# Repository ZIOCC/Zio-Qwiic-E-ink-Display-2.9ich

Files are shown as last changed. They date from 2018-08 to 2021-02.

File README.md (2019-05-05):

# Zio Qwiic E-Ink Display 2.9"

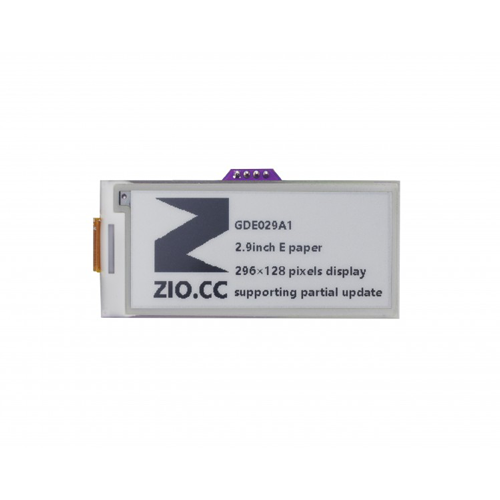
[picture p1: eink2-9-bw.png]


> This product can be available for purchase [here](https://www.smart-prototyping.com/%20Zio-Qwiic-E-ink-Display-I2C).

##### Description

An E-ink module is great, how about to make it even nicer? Here we go! Instead of using SPI protocol, we created this I2C E-ink display to join our Qwiic family. So you can just daisy chain this E-ink display just like the other Qwiic modules!

Nothing fancy here, we add a STM32 as the gateway, it can communicate with I2C system, then drive E-ink display to refresh content by SPI protocol.

In order to inherit the ultra low power consuming feature of the E-ink display, we let the STM32 IC go into deep sleep mode (2uA power consuming) and add an I2C chip that is used for waking STM32 up.

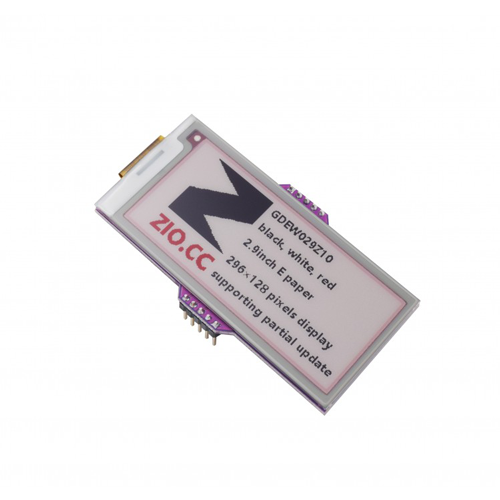
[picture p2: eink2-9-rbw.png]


> This product can be available for purchase [here](https://www.smart-prototyping.com/Zio-E-Ink-Display-2-9-in-Black-White-Red).

Tired of using boring black and white E-ink display? Let’s add a spicy color to it! This is a 2.9 inch Red-Black-white E-ink display with 296x128 pixels resolution.

The red is good, but not always, because of the limitation of the E-ink display technology, the refresh time for Red E-ink display is much longer than Black-White version, this E-ink display refresh time is 12 secs! Let’s hope the technology will solve this soon, until then, enjoy this red E-ink first!

##### Usage:

* Price tag for supermarket, shop
* Industry controller device
* Low power Consumption product and project

###### About Zio
> Zio is a new line of open sourced, compact, and grid layout boards, fully integrated for Arduino and Qwiic ecosystem. Designed ideally for wearables, robotics, small-space limitations or other on the go projects. Check out other awesome Zio products [here](https://www.smart-prototyping.com/Zio).

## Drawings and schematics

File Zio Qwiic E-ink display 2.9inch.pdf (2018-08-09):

1uF ±10% 25V | 1uF ±10% ⁵⁰V 1uF ±10% ⁵⁰V GND
GND100nF ±10% ⁵⁰V | 100nF ±10% ⁵⁰V | 10K ±1% | 10K ±1% | 10K ±1%

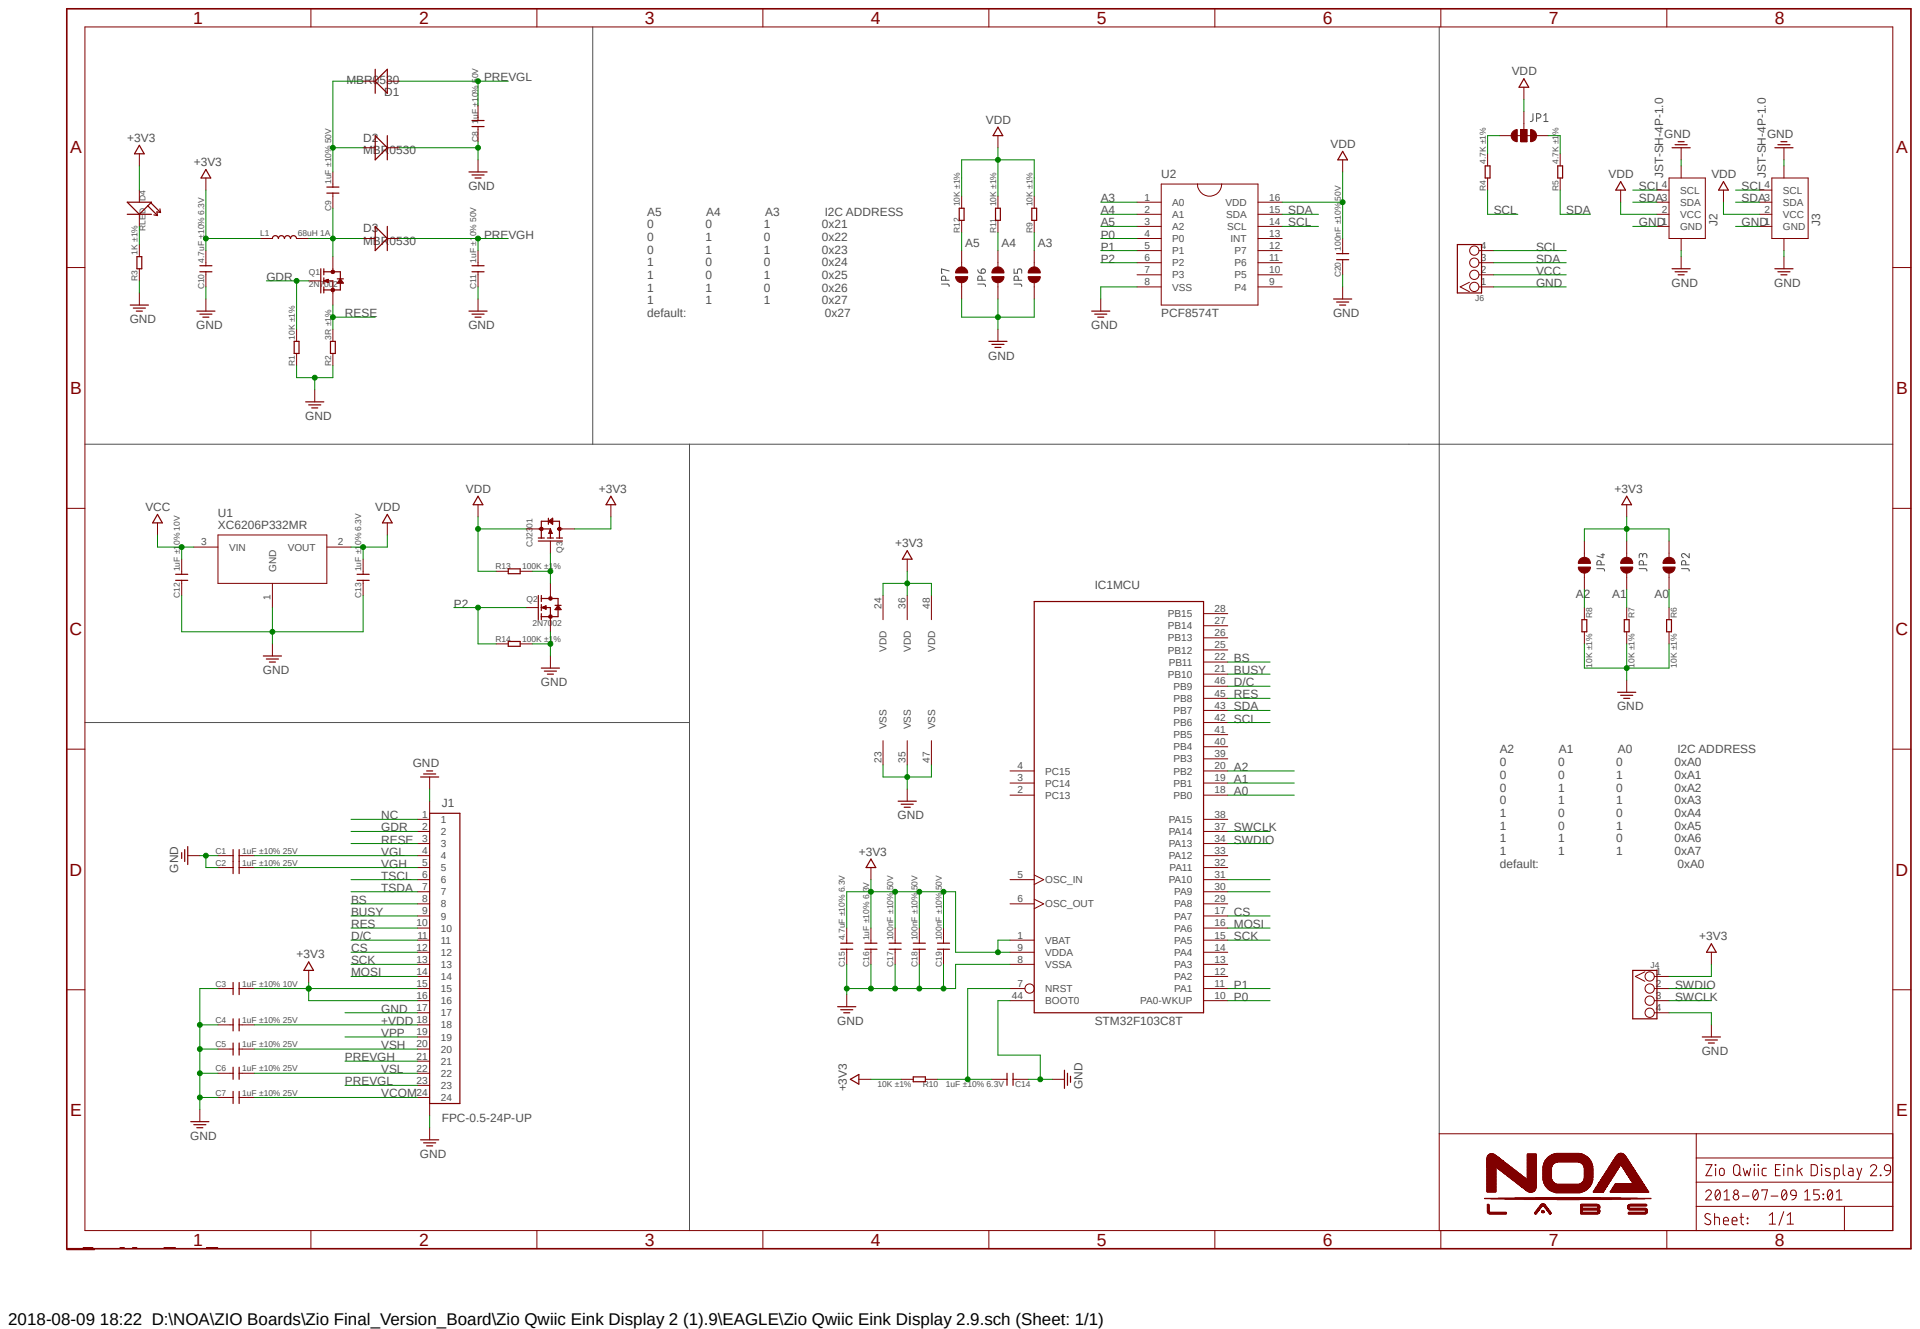
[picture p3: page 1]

VDD | VDD

4 J3 JST⁻SH⁻⁴P⁻¹.0 GND

2018-08-09 18:22 D:\NOA\ZIO Boards\Zio Final_Version_Board\Zio Qwiic Eink Display 2 (1).9\EAGLE\Zio Qwiic Eink Display 2.9.sch (Sheet: 1/1)

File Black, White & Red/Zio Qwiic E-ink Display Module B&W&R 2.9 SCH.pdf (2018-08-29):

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

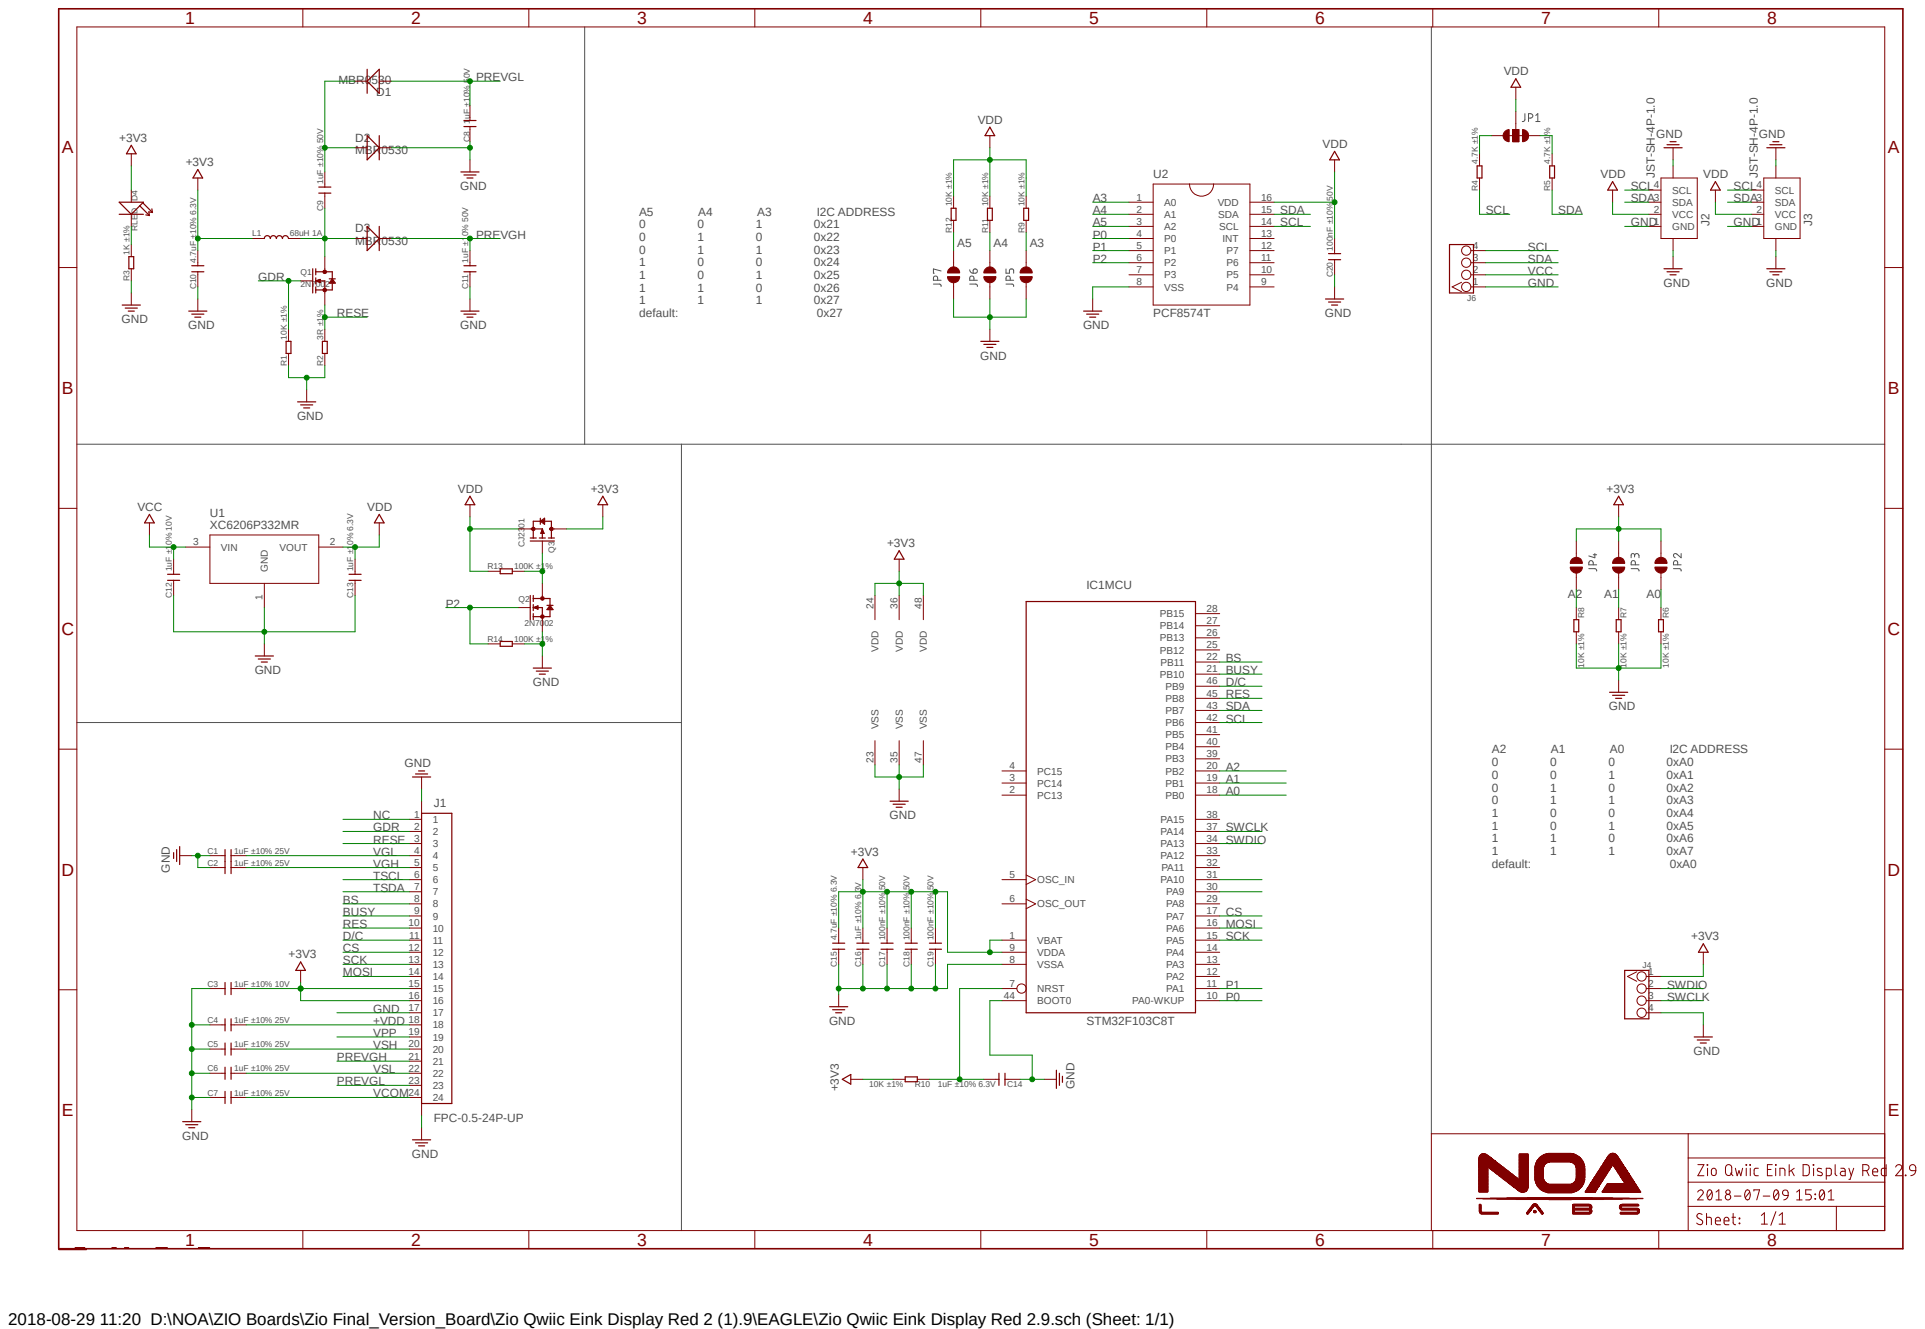
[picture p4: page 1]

VDD | VDD

4 J3 JST⁻SH⁻⁴P⁻¹.0 GND

2018-08-29 11:20 D:\NOA\ZIO Boards\Zio Final_Version_Board\Zio Qwiic Eink Display Red 2 (1).9\EAGLE\Zio Qwiic Eink Display Red 2.9.sch (Sheet: 1/1)

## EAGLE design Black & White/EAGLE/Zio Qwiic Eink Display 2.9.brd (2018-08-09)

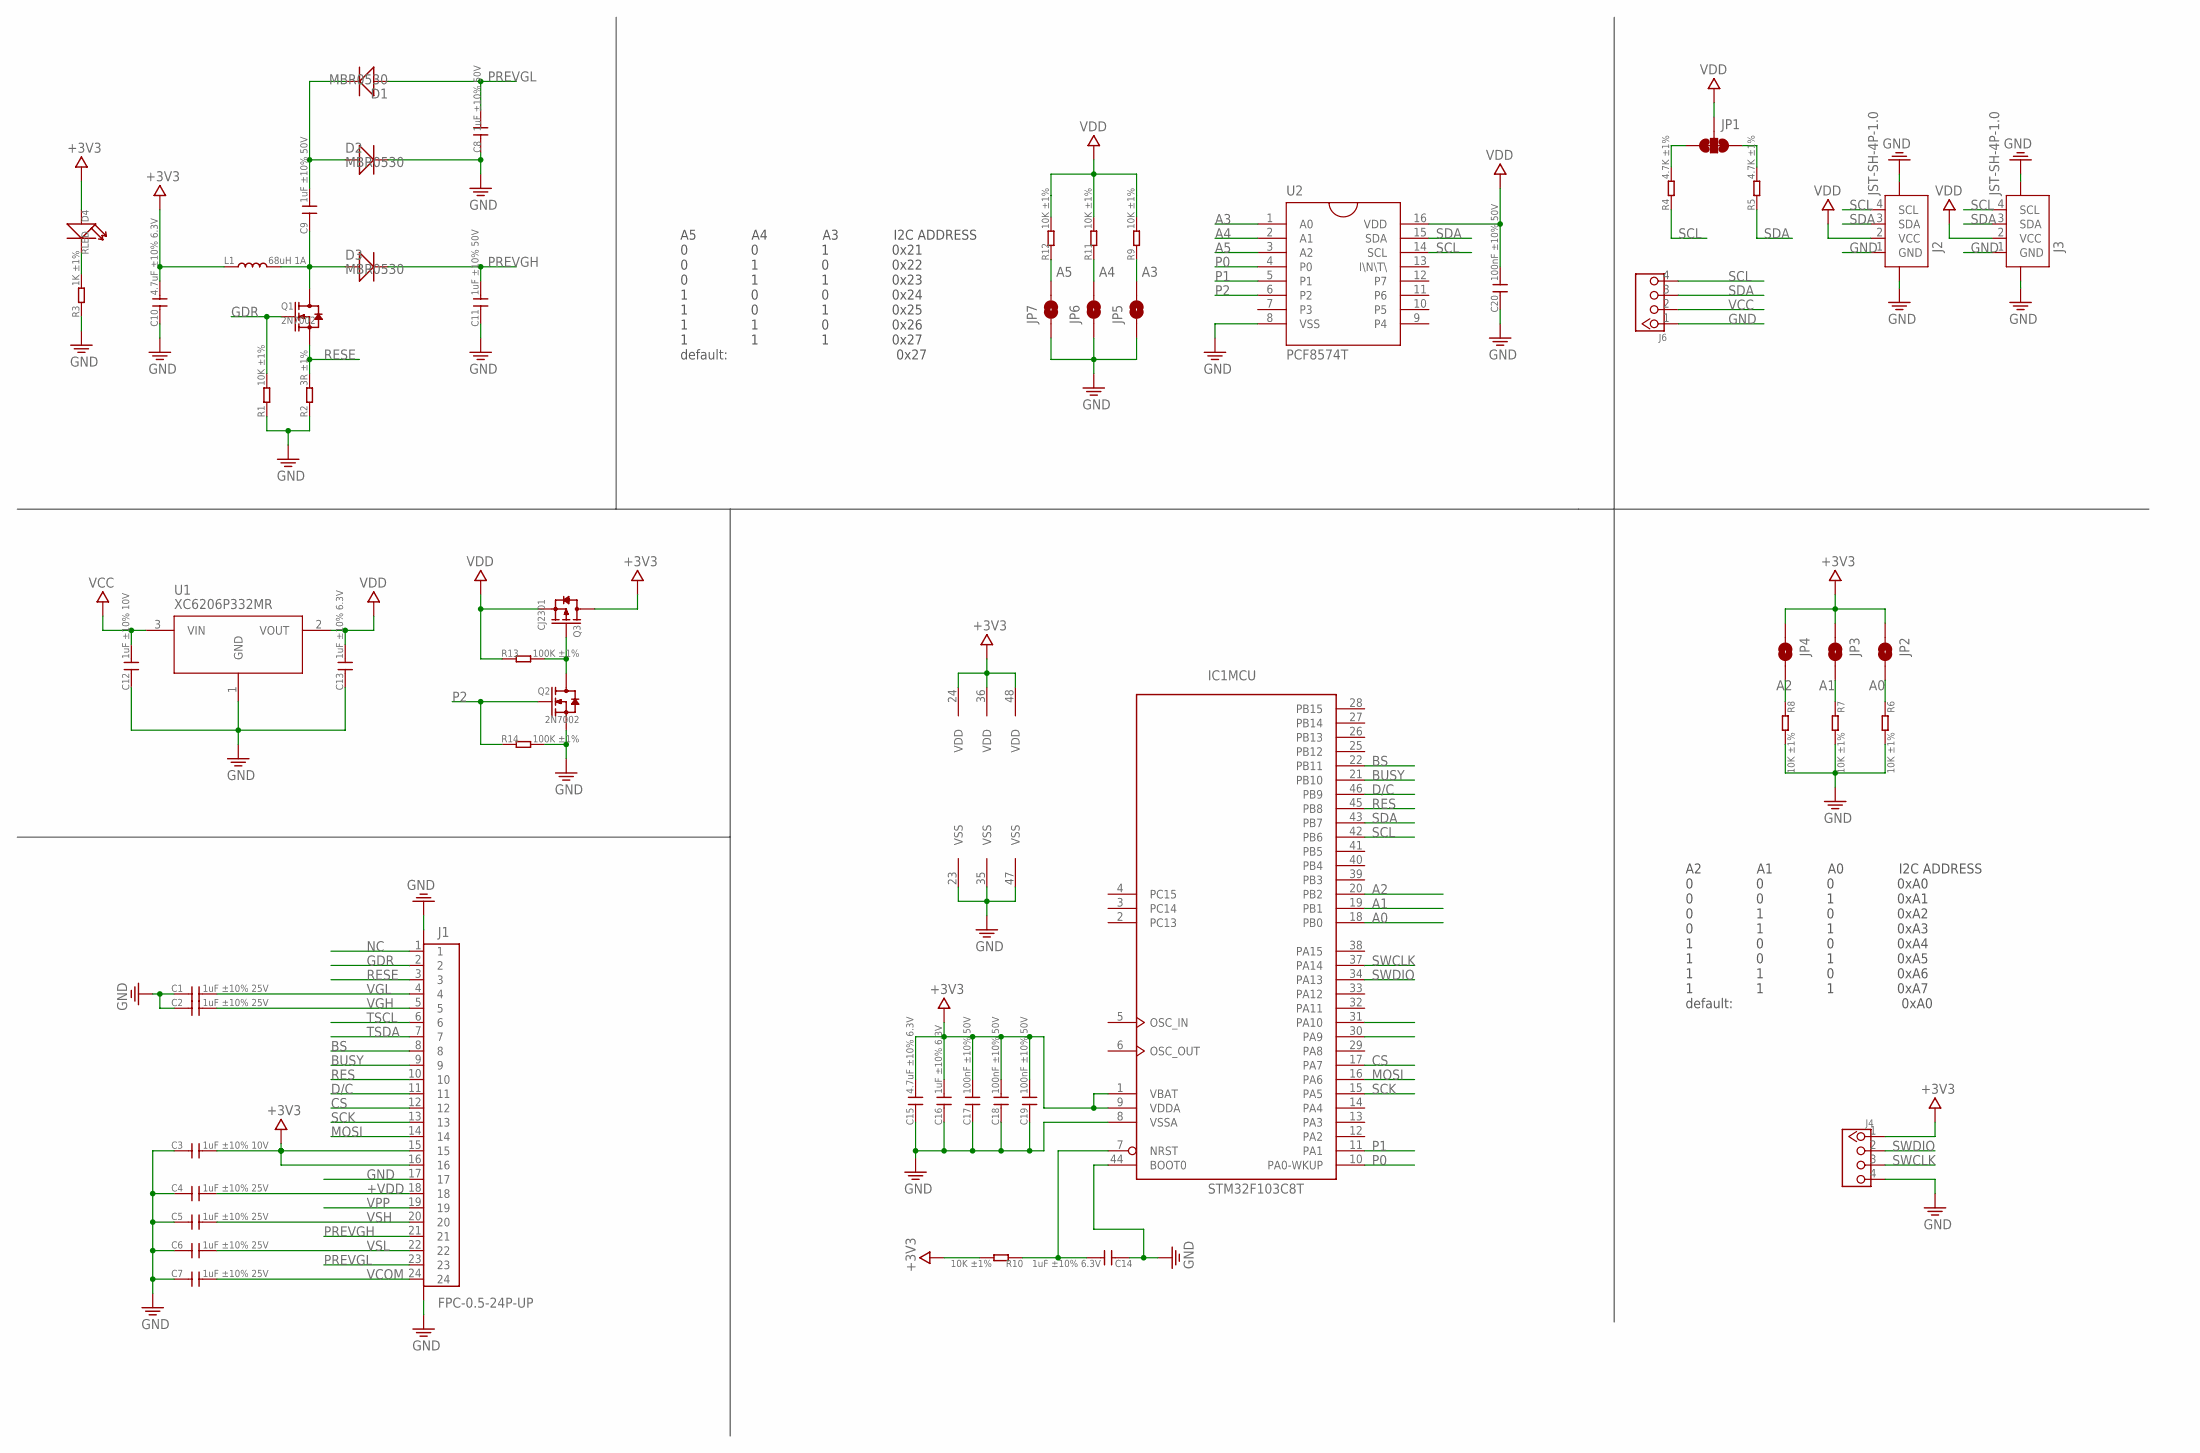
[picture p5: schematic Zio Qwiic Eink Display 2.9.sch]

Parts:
C1, C2, C4, C5, C6, C7: 1uF ±10% 25V; C0603
C3, C12: 1uF ±10% 10V; C0603
C8: 1uF ±10% 50V; 0603
C9, C11: 1uF ±10% 50V; C0603
C10, C15: 4.7uF ±10% 6.3V; C0603
C13, C14, C16: 1uF ±10% 6.3V; C0603
C17, C18, C19, C20: 100nF ±10% 50V; C0603
D1, D2, D3: MBR0530; SOD123
D4: RLED; LED-0603
IC1: STM32F103C8T; LQFP48
J1: FPC-0.5-24P-UP; FPC-0.5-24P_UP
J2, J3: JST-SH-4P-1.0; JST-SH-4P
J4: HEADER-4P-2.54-SMD; 4P-2.54-SMD-180
J6: HEADER-4P-60/35MIL; 4P-65/35MIL
JP1: SMT-JUMPER_3_2-NC_TRACE
JP2, JP3, JP4, JP5, JP6, JP7: JUMPER-SMT_2_NC_PASTE_NOCREM; SMT-JUMPER_2_NC_PASTE_SILK_NOCREM
L1: 68uH 1A; L3012
Q1, Q2: 2N7002; SOT23
Q3: CJ2301; SOT23
R1, R6, R7, R8, R9, R10, R11, R12: 10K ±1%; R0603
R2: 3R ±1%; R0603
R3: 1K ±1%; R0603
R4, R5: 4.7K ±1%; R0603
R13, R14: 100K ±1%; R0603
U1: XC6206P332MR; SOT23
U2: PCF8574T; SO16-W

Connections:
+3V3: C3.2, C10.2, C15.2, C16.2, C17.2, C18.2, C19.2, D4.+, IC1.1 (VBAT), IC1.9 (VDDA), IC1.24 (VDD), IC1.36 (VDD), IC1.48 (VDD), J1.15, J1.16, J4.1, JP2.1, JP3.1, JP4.1, L1.1, Q3.3 (D), R10.2
+VDD: C4.2, J1.18
A0: IC1.18 (PB0), JP2.2, R6.1
A1: IC1.19 (PB1), JP3.2, R7.1
A2: IC1.20 (PB2), JP4.2, R8.1
A3: JP5.2, R9.1, U2.1 (A0)
A4: JP6.2, R11.1, U2.2 (A1)
A5: JP7.2, R12.1, U2.3 (A2)
BS: IC1.22 (PB11), J1.8
BUSY: IC1.21 (PB10), J1.9
CS: IC1.17 (PA7), J1.12
D/C: IC1.46 (PB9), J1.11
GDR: J1.2, Q1.1 (G), R1.2
GND: C1.1, C2.1, C3.1, C4.1, C5.1, C6.1, C7.1, C8.1, C10.1, C11.1, C12.1, C13.1, C14.1, C15.1, C16.1, C17.1, C18.1, C19.1, C20.1, D2.-, IC1.8 (VSSA), IC1.23 (VSS), IC1.35 (VSS), IC1.44 (BOOT0), IC1.47 (VSS), J1.17, J1.25 (G1), J1.26 (G2), J2.1 (GND), J2.NC1 (5), J2.NC2 (6), J3.1 (GND), J3.NC1 (5), J3.NC2 (6), J4.4, J6.1, JP5.1, JP6.1, JP7.1, Q2.2 (S), R1.1, R2.1, R3.1, R6.2, R7.2, R8.2, R14.2, U1.1 (GND), U2.8 (VSS)
MOSI: IC1.16 (PA6), J1.14
unnamed: C9.2, D1.-, D2.+
unnamed: C9.1, D3.+, L1.2, Q1.3 (D)
unnamed: C14.2, IC1.7 (NRST), R10.1
unnamed: JP1.3, R4.2
unnamed: D4.-, R3.2
unnamed: JP1.1, R5.2
unnamed: Q2.3 (D), Q3.1 (G), R13.2
NC: J1.1
P0: IC1.10 (PA0-WKUP), U2.4 (P0)
P1: IC1.11 (PA1), U2.5 (P1)
P2: Q2.1 (G), R14.1, U2.6 (P2)
PREVGH: C11.2, D3.-, J1.21
PREVGL: C8.2, D1.+, J1.23
RES: IC1.45 (PB8), J1.10
RESE: J1.3, Q1.2 (S), R2.2
SCK: IC1.15 (PA5), J1.13
SCL: IC1.42 (PB6), J2.4 (SCL), J3.4 (SCL), J6.4, R4.1, U2.14 (SCL)
SDA: IC1.43 (PB7), J2.3 (SDA), J3.3 (SDA), J6.3, R5.1, U2.15 (SDA)
SWCLK: IC1.37 (PA14), J4.3
SWDIO: IC1.34 (PA13), J4.2
TSCL: J1.6
TSDA: J1.7
VCC: C12.2, J6.2, U1.3 (VIN)
VCOM: C7.2, J1.24
VDD: C13.2, C20.2, J2.2 (VCC), J3.2 (VCC), JP1.2, Q3.2 (S), R9.2, R11.2, R12.2, R13.1, U1.2 (VOUT), U2.16 (VDD)
VGH: C2.2, J1.5
VGL: C1.2, J1.4
VPP: J1.19
VSH: C5.2, J1.20
VSL: C6.2, J1.22

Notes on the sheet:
A2 A1 A0 I2C ADDRESS 0 0 0 0xA0 0 0 1 0xA1 0 1 0 0xA2 0 1 1 0xA3 1 0 0 0xA4 1 0 1 0xA5 1 1 0 0xA6 1 1 1 0xA7 default: 0xA0
A5 A4 A3 I2C ADDRESS 0 0 1 0x21 0 1 0 0x22 0 1 1 0x23 1 0 0 0x24 1 0 1 0x25 1 1 0 0x26 1 1 1 0x27 default: 0x27

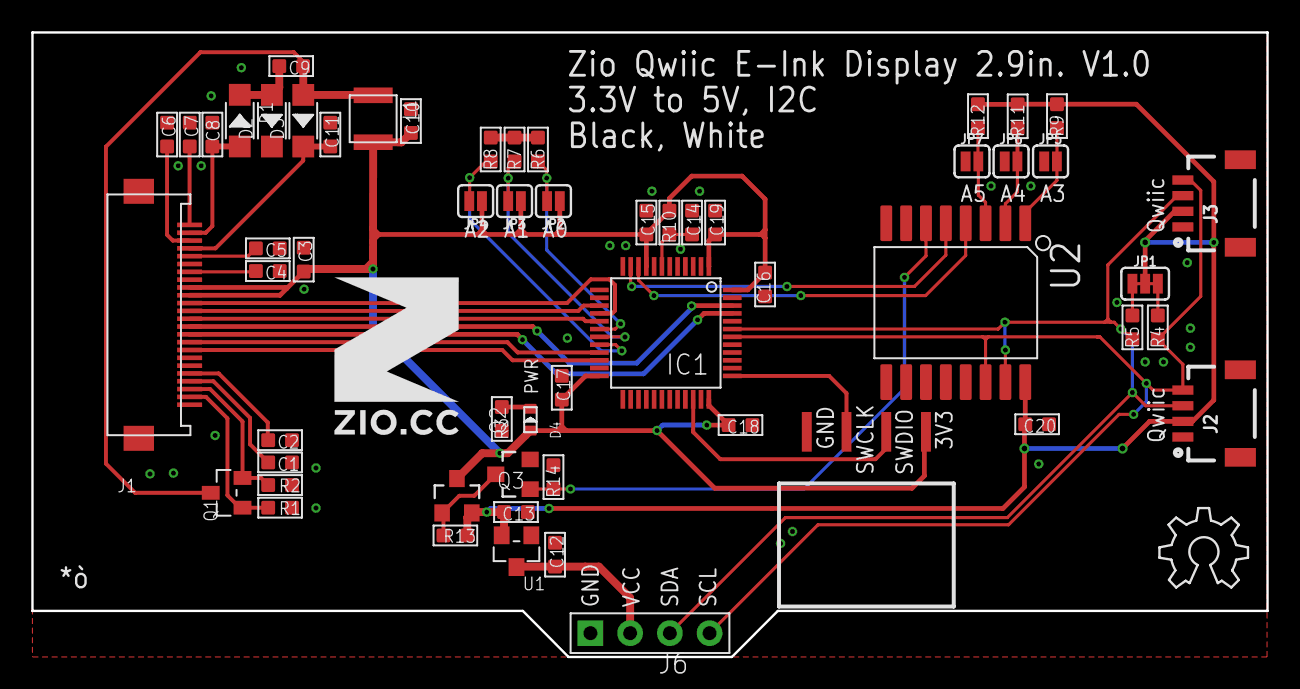
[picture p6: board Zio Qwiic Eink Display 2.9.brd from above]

Board: 2 copper layers, 79.0 x 39.9 mm, 59 parts (0 on the bottom side), 41 nets.

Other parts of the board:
U$10: OSHW_6X200_NOTEXT
U$20: 10MM

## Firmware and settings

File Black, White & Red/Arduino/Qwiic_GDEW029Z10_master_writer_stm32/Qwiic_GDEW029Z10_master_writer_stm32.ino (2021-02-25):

#include <Wire.h>
#include"I2CIO.h"
I2CIO IO;
const unsigned char  Pic_Black[] PROGMEM=
{
0XFF,0XFF,0XFF,0XFF,0XFF,0XFF,0XFF,0XFF,0XFF,0XFF,0XFF,0XFF,0XFF,0XFF,0XFF,0XFF,
0XFF,0XFF,0XFF,0XFF,0XFF,0XFF,0XFF,0XFF,0XFF,0XFF,0XFF,0XFF,0XFF,0XFF,0XFF,0XFF,
0XFF,0XFF,0XFF,0XFF,0XFF,0XFF,0XFF,0XFF,0XFF,0XFF,0XFF,0XFF,0XFF,0XFF,0XFF,0XFF,
0XFF,0XFF,0XFF,0XFF,0XFF,0XFF,0XFF,0XFF,0XFF,0XFF,0XFF,0XFF,0XFF,0XFF,0XFF,0XFF,
0XFF,0XFF,0XFF,0XFF,0XFF,0XFF,0XFF,0XFF,0XFF,0XFF,0XFF,0XFF,0XFF,0XFF,0XFF,0XFF,
0XFF,0XFF,0XFF,0XFF,0XFF,0XFF,0XFF,0XFF,0XFF,0XFF,0XFF,0XFF,0XFF,0XFF,0XFF,0XFF,
0XFF,0XFF,0XFF,0XFF,0XFF,0XFF,0XFF,0XFF,0XFF,0XFF,0XFF,0XFF,0XFF,0XFF,0XFF,0XFF,
0XFF,0XFF,0XFF,0XFF,0XFF,0XFF,0XFF,0XFF,0XFF,0XFF,0XFF,0XFF,0XFF,0XFE,0X3F,0XFF,
0XFF,0XFF,0XFF,0XFF,0XFF,0XFF,0XFF,0XFF,0XFF,0XFF,0XFF,0XFF,0XFF,0XFC,0X27,0XFF,
0XFF,0XFF,0XFF,0XFF,0XFF,0XFF,0XFF,0XFF,0XFF,0XFF,0XFF,0XFF,0XFF,0XFC,0XA7,0XFF,
0XFF,0XFF,0XFF,0XFF,0XFF,0XFF,0XFF,0XFF,0XFF,0XFF,0XFF,0XFF,0XFF,0XFC,0XA7,0XFF,
0XFF,0XFF,0XFF,0XFF,0XFF,0XFF,0XFF,0XFF,0XFF,0XFF,0XFF,0XFF,0XFF,0XFC,0XA7,0XFF,
0XFF,0XFF,0XFF,0XFF,0XFF,0XFF,0XFF,0XFF,0XFF,0XFF,0XFF,0XFF,0XFF,0XFE,0X07,0XFF,
0XFF,0XFF,0XFF,0XFF,0XFF,0XFF,0XFF,0XFF,0XFF,0XFF,0XFF,0XFF,0XFF,0XFF,0X0F,0XFF,
0XFF,0XFF,0XFF,0XFF,0XFF,0XFF,0XFF,0XFF,0XFF,0XFF,0XFF,0XFF,0XFF,0XFF,0XFF,0XFF,
0XFF,0XFF,0XFF,0XFF,0XFF,0XFF,0XFF,0XFF,0XFF,0XFF,0XFF,0XFF,0XFF,0XFC,0XE7,0XFF,
0XFF,0XFF,0XFF,0XFF,0XFF,0XFF,0XFF,0XFF,0XFF,0XFF,0XFF,0XFF,0XFF,0XFC,0XE7,0XFF,
0XFF,0XFF,0XFF,0XFF,0XFF,0XFF,0XFF,0XFF,0XFF,0XFF,0XFF,0XFF,0XFF,0XF0,0X07,0XFF,
0XFF,0XFF,0XFF,0XFF,0XFF,0XFF,0XFF,0XFF,0XFF,0XFF,0XFF,0XFF,0XFF,0XF0,0X0F,0XFF,
0XFF,0XFF,0XFF,0XFF,0XFF,0XFF,0XFF,0XFF,0XFF,0XFF,0XFF,0XFF,0XFF,0XFC,0XFF,0XFF,
0XFF,0XFF,0XFF,0XFF,0XFF,0XFF,0XFF,0XFF,0XFF,0XFF,0XFF,0XFF,0XFF,0XFF,0XFF,0XFF,
0XFF,0XFF,0XFF,0XFF,0XFF,0XFF,0XFF,0XFF,0XFF,0XFF,0XFF,0XFF,0XFF,0XFE,0X07,0XFF,
0XFF,0XFF,0XFF,0XFF,0XFF,0XFF,0XFF,0XFF,0XFF,0XFF,0XFF,0XFF,0XFF,0XFC,0X07,0XFF,
0XFF,0XFF,0XFF,0XFF,0XFF,0XFF,0XFF,0XFF,0XFF,0XFF,0XFF,0XFF,0XFF,0XFC,0XAF,0XFF,
0XFF,0XFF,0XFF,0XFF,0XFF,0XFF,0XFF,0XFF,0XFF,0XFF,0XFF,0XFF,0XFF,0XFC,0XA7,0XFF,
0XFF,0XFF,0XFF,0XFF,0XFF,0XFF,0XFF,0XFF,0XFF,0XFF,0XFF,0XFF,0XFF,0XFC,0XA7,0XFF,
0XFF,0XFF,0XFF,0XFF,0XFF,0XFF,0XFF,0XFF,0XFF,0XFF,0XFE,0X3F,0XFF,0XFC,0X87,0XFF,
0XFF,0XFF,0XFF,0XFF,0XFF,0XFF,0XFF,0XFF,0XFF,0XFF,0XFE,0X07,0XFF,0XFF,0XCF,0XFF,
0XFF,0XFF,0XFF,0XFF,0XFF,0XFF,0XFF,0XFF,0XFF,0XFF,0XFF,0XE0,0XFF,0XFF,0XFF,0XFF,
0XFF,0XFF,0XFF,0XFF,0XFF,0XFF,0XFF,0XFF,0XFF,0XFF,0XFF,0XC0,0X7F,0XE0,0X07,0XFF,
0XFF,0XFF,0XFF,0XFF,0XFF,0XFF,0XFF,0XFF,0XFF,0XFF,0XFE,0X06,0X3F,0XE0,0X07,0XFF,
0XFF,0XFF,0XFF,0XFF,0XFF,0XFF,0XFF,0XFF,0XFF,0XFF,0XFE,0X1F,0X3F,0XFE,0XEF,0XFF,
0XFF,0XFF,0XFF,0XFF,0XFF,0XFF,0XFF,0XFF,0XFF,0XFF,0XFE,0XFF,0X3F,0XFC,0XE7,0XFF,
0XFF,0XFF,0XFF,0XFF,0XFF,0XFF,0XFF,0XFF,0XFF,0XFF,0XFF,0XFF,0XFF,0XFC,0XE7,0XFF,
0XFF,0XFF,0XFF,0XFF,0XFF,0XFF,0XFF,0XFF,0XFF,0XFF,0XFF,0X03,0XFF,0XFC,0X07,0XFF,
0XFF,0XFF,0XFF,0XFF,0XFF,0XFF,0XFF,0XFF,0XFF,0XFF,0XFE,0X03,0XFF,0XFF,0X0F,0XFF,
0XFF,0XFF,0XFF,0XFF,0XFF,0XFF,0XFF,0XFF,0XFF,0XFF,0XFE,0X57,0XFF,0XFF,0XFF,0XFF,
0XFF,0XFF,0XFF,0XFF,0XFF,0XFF,0XFF,0XFF,0XFF,0XFF,0XFE,0X53,0XFF,0XFF,0XFF,0XFF,
0XFF,0XFF,0XFF,0XFF,0XFF,0XFF,0XFF,0XFF,0XFF,0XFF,0XFE,0X53,0XFF,0XFE,0X1F,0XFF,
0XFF,0XFF,0XFF,0XFF,0XFF,0XFF,0XFF,0XFF,0XFF,0XFF,0XFE,0X43,0XFF,0XFC,0X07,0XFF,
0XFF,0XFF,0XFF,0XFF,0XFF,0XFF,0XFF,0XFF,0XFF,0XFF,0XFF,0XE7,0XFF,0XFC,0XE7,0XFF,
0XFF,0XFF,0XFF,0XFF,0XFF,0XFF,0XFF,0XFF,0XFF,0XFF,0XFF,0XFF,0XFF,0XFC,0XE7,0XFF,
0XFF,0XFF,0XFF,0XFF,0XFF,0XFF,0XFF,0XFF,0XFF,0XFF,0XF0,0X03,0XFF,0XFE,0XEF,0XFF,
0XFF,0XFF,0XFF,0XFF,0XFF,0XFF,0XFF,0XFF,0XFF,0XFF,0XF0,0X03,0XFF,0XFC,0X00,0XFF,
0XFF,0XFF,0XFF,0XFF,0XFF,0XFF,0XFF,0XFF,0XFF,0XFF,0XFF,0XFF,0XFF,0XFC,0X00,0XFF,
0XFF,0XFF,0XFF,0XFF,0XFF,0XFF,0XFF,0XFF,0XFF,0XFF,0XFF,0XFF,0XFF,0XFF,0XFF,0XFF,
0XFF,0XFF,0XFF,0XFF,0XFF,0XFF,0XFF,0XFF,0XFF,0XFF,0XFF,0X0F,0XFF,0XFF,0XFF,0XFF,
0XFF,0XFF,0XFF,0XFF,0XFF,0XFF,0XFF,0XFF,0XFF,0XFF,0XFE,0X03,0XFF,0XFC,0X07,0XFF,
0XFF,0XFF,0XFF,0XFF,0XFF,0XFF,0XFF,0XFF,0XFF,0XFF,0XFE,0X73,0XFF,0XFC,0X07,0XFF,
0XFF,0XFF,0XFF,0XFF,0XFF,0XFF,0XFF,0XFF,0XFF,0XFF,0XFE,0X73,0XFF,0XFF,0XEF,0XFF,
0XFF,0XFF,0XFF,0XFF,0XFF,0XFF,0XFF,0XFF,0XFF,0XFF,0XFF,0X77,0XFF,0XFF,0XE7,0XFF,
0XFF,0XFF,0XFF,0XFF,0XFF,0XFF,0XFF,0XFF,0XFF,0XFF,0XFE,0X00,0X7F,0XFC,0X07,0XFF,
0XFF,0XFF,0XFF,0XFF,0XFF,0XFF,0XFF,0XFF,0XFF,0XFF,0XFE,0X00,0X7F,0XFC,0X0F,0XFF,
0XFF,0XFF,0XFF,0XFF,0XFF,0XFF,0XFF,0XFF,0XFF,0XFF,0XFF,0XFF,0XFF,0XFF,0XFF,0XFF,
0XFF,0XFF,0XFF,0XFF,0XFF,0XFF,0XFF,0XFF,0XFF,0XFF,0XFE,0X67,0XFF,0XFF,0XFF,0XFF,
0XFF,0XFF,0XFF,0XFF,0XFF,0XFF,0XFF,0XFF,0XFF,0XFF,0XFE,0X43,0XFF,0XFF,0XFF,0XFF,
0XFF,0XFF,0XFF,0XFF,0XFF,0XFF,0XFF,0XFF,0XFF,0XFF,0XFE,0X43,0XFF,0XFF,0XFF,0XFF,
0XFF,0XFF,0XFF,0XFF,0XFF,0XFF,0XFF,0XFF,0XFF,0XFF,0XFE,0X13,0XFF,0XFF,0XFF,0XFF,
0XFF,0XFF,0XFF,0XFF,0XFF,0XFF,0XFF,0XFF,0XFF,0XFF,0XFF,0X13,0XFF,0XFF,0XFF,0XFF,
0XFF,0XFF,0XFF,0XFF,0XFF,0XFF,0XFF,0XFF,0XFF,0XFF,0XFF,0XFF,0XFF,0XE0,0X07,0XFF,
0XFF,0XFF,0XFF,0XFF,0XFF,0XFF,0XFF,0XFF,0XFF,0XFF,0XFF,0XFF,0XFF,0XE0,0X07,0XFF,
0XFF,0XFF,0XFF,0XFF,0XFF,0XFF,0XFF,0XFF,0XFF,0XFF,0XF2,0X03,0XFF,0XFF,0XFF,0XFF,
0XFF,0XFF,0XFF,0XFF,0XFF,0XFF,0XFF,0XFF,0XFF,0XFF,0XF2,0X03,0XFF,0XFF,0XFF,0XFF,
0XFF,0XFF,0XFF,0XFF,0XFF,0XFF,0XFF,0XFF,0XFF,0XFF,0XFF,0XFF,0XFF,0XFE,0X07,0XFF,
0XFF,0XFF,0XFF,0XFF,0XFF,0XFF,0XFF,0XFF,0XFF,0XFF,0XFF,0XFF,0XFF,0XFC,0X07,0XFF,
0XFF,0XFF,0XFF,0XFF,0XFF,0XFF,0XFF,0XFF,0XFF,0XFF,0XF0,0X03,0XFF,0XFC,0XAF,0XFF,
0XFF,0XFF,0XFF,0XFF,0XFF,0XFF,0XFF,0XFF,0XFF,0XFF,0XF0,0X03,0XFF,0XFC,0XA7,0XFF,
0XFF,0XFF,0XFF,0XFF,0XFF,0XFF,0XFF,0XFF,0XFF,0XFF,0XFF,0X77,0XFF,0XFC,0XA7,0XFF,
0XFF,0XFF,0XFF,0XFE,0X00,0X7F,0XFF,0XFF,0XFF,0XFF,0XFE,0X73,0XFF,0XFC,0X87,0XFF,
0XFF,0XFF,0XFF,0XFE,0X00,0X7F,0XFF,0XFF,0XFF,0XFF,0XFE,0X73,0XFF,0XFF,0XCF,0XFF,
0XFF,0XFF,0XFF,0XFF,0XEE,0XFF,0XFF,0XFF,0XFF,0XFF,0XFE,0X03,0XFF,0XFF,0XFF,0XFF,
0XFF,0XFF,0XFF,0XFF,0XCE,0X7F,0XFF,0XFF,0XFF,0XFF,0XFF,0X87,0XFF,0XE4,0X07,0XFF,
0XFF,0XFF,0XFF,0XFF,0XCE,0X7F,0XFF,0XFF,0XFF,0XFF,0XFF,0XFF,0XFF,0XE4,0X07,0XFF,
0XFF,0XFF,0XFF,0XFF,0XC0,0X7F,0XFF,0XFF,0XFF,0XFF,0XFF,0XFF,0XFF,0XFF,0XFF,0XFF,
0XFF,0XFF,0XFF,0XFF,0XF0,0XFF,0XFF,0XFF,0XFF,0XFF,0XFF,0XFF,0XFF,0XFC,0XE7,0XFF,
0XFF,0XFF,0XFF,0XFF,0XFF,0XFF,0XFF,0XFF,0XFF,0XFF,0XFF,0XFF,0XFF,0XFC,0XE7,0XFF,
0XFF,0XFF,0XFF,0XFF,0XE3,0XFF,0XFF,0XFF,0XFF,0XFF,0XFF,0XFF,0XFF,0XF0,0X07,0XFF,
0XFF,0XFF,0XFF,0XFF,0XC2,0X7F,0XFF,0XE7,0XFF,0XFF,0XFE,0X67,0XFF,0XF0,0X0F,0XFF,
0XFF,0XFF,0XFF,0XFF,0XCA,0X7F,0XFF,0XF7,0XFF,0XFF,0XFE,0X43,0XFF,0XFC,0XFF,0XFF,
0XFF,0XFF,0XFF,0XFF,0XCA,0X7F,0XFF,0XE0,0X3F,0XFF,0XFE,0X43,0XFF,0XFF,0XFF,0XFF,
0XFF,0XFF,0XFF,0XFF,0XCA,0X7F,0XFF,0XE0,0X3F,0XFF,0XFE,0X13,0XFF,0XFC,0XFF,0XFF,
0XFF,0XFF,0XFF,0XFF,0XE0,0X7F,0XFF,0XFF,0XFF,0XFF,0XFF,0X13,0XFF,0XFE,0XFF,0XFF,
0XFF,0XFF,0XFF,0XFF,0XF0,0XFF,0XFF,0XF1,0XFF,0XFF,0XFF,0XFF,0XFF,0XFC,0X07,0XFF,
0XFF,0XFF,0XFF,0XFF,0XFF,0XFF,0XFF,0XE1,0X3F,0XFF,0XFF,0XFF,0XFF,0XFC,0X07,0XFF,
0XFF,0XFF,0XFF,0XFF,0XFF,0XFF,0XFF,0XE5,0X3F,0XFF,0XF0,0X03,0XFF,0XFF,0XFF,0XFF,
0XFF,0XFF,0XFF,0XFF,0XCF,0XFF,0XFF,0XE5,0X3F,0XFF,0XF0,0X03,0XFF,0XFF,0XFF,0XFF,
0XFF,0XFF,0XFF,0XFF,0XEF,0XFF,0XFF,0XE5,0X3F,0XFF,0XFF,0XFF,0XFF,0XFE,0X07,0XFF,
0XFF,0XFF,0XFF,0XFF,0XC0,0X7F,0XFF,0XF0,0X3F,0XFF,0XFF,0X1F,0XFF,0XFC,0X07,0XFF,
0XFF,0XFF,0XFF,0XFF,0XC0,0X7F,0XFF,0XF8,0X7F,0XFF,0XFE,0X13,0XFF,0XFC,0XAF,0XFF,
0XFF,0XFF,0XFF,0XFF,0XFF,0XFF,0XFF,0XFF,0XFF,0XFF,0XFE,0X53,0XFF,0XFC,0XA7,0XFF,
0XFF,0XE0,0X7F,0XFF,0XFF,0XFF,0XFF,0XFF,0XFF,0XFF,0XFE,0X53,0XFF,0XFC,0XA7,0XFF,
0XFF,0XC0,0X3F,0XFF,0XFF,0XFF,0XFF,0XF0,0XFF,0XFF,0XFE,0X53,0XFF,0XFC,0X87,0XFF,
0XFF,0X8F,0X1F,0XFF,0XFF,0XFF,0XFF,0XE0,0X3F,0XFF,0XFF,0X03,0XFF,0XFF,0XCF,0XFF,
0XFF,0X9F,0X9F,0XFF,0XFF,0XFF,0XFF,0XE7,0X3F,0XFF,0XFF,0X87,0XFF,0XFF,0XFF,0XFF,
0XFF,0X8F,0X1F,0XFF,0XFF,0XFF,0XFF,0XE7,0X3F,0XFF,0XFF,0XFF,0XFF,0XFE,0X1F,0XFF,
0XFF,0XC0,0X3F,0XFF,0XFF,0X7F,0XFF,0XF7,0X7F,0XFF,0XFF,0XFF,0XFF,0XFC,0X07,0XFF,
0XFF,0XE0,0X7F,0XFF,0XFF,0X1F,0XFF,0XE0,0X07,0XFF,0XFE,0XFB,0XFF,0XFC,0XE7,0XFF,
0XFF,0XFF,0XFF,0XFF,0XFF,0X1F,0XFF,0XE0,0X07,0XFF,0XFE,0X63,0XFF,0XFC,0XE7,0XFF,
0XFF,0XFF,0XFF,0XFF,0XE3,0XFF,0XFF,0XFF,0XFF,0XFF,0XFF,0X07,0XFF,0XFE,0XEF,0XFF,
0XFF,0XFF,0XFF,0XFF,0XC2,0X7F,0XFF,0XFF,0XFF,0XFF,0XFF,0X9F,0XFF,0XFC,0X00,0XFF,
0XFF,0XFF,0XFF,0XFF,0XCA,0X7F,0XFF,0XF0,0X3F,0XFF,0XFE,0X07,0XFF,0XFC,0X00,0XFF,
0XFF,0X80,0X1F,0XFF,0XCA,0X7F,0XFF,0XE0,0X3F,0XFF,0XFE,0X73,0XFF,0XFF,0XFF,0XFF,
0XFF,0X80,0X1F,0XFF,0XCA,0X7F,0XFF,0XE5,0X7F,0XFF,0XFE,0XFB,0XFF,0XFF,0XFF,0XFF,
0XFF,0XDF,0XFF,0XFF,0XE0,0X7F,0XFF,0XE5,0X3F,0XFF,0XFF,0XFF,0XFF,0XFF,0XFF,0XFF,
0XFF,0XCF,0XFF,0XFF,0XF0,0XFF,0XFF,0XE5,0X3F,0XFF,0XF2,0X03,0XFF,0XFF,0XFF,0XFF,
0XFF,0XFF,0XFF,0XFF,0XFF,0XFF,0XFF,0XE4,0X3F,0XFF,0XF2,0X03,0XFF,0XFF,0XFF,0XFF,
0XFF,0X9F,0X9F,0XFF,0XCE,0X7F,0XFF,0XFE,0X7F,0XFF,0XFF,0XFF,0XFF,0XFF,0XFF,0XFF,
0XFF,0X8F,0X9F,0XFF,0XCE,0X7F,0XFF,0XFF,0XFF,0XFF,0XFF,0XFF,0XFF,0XFC,0X03,0XFF,
0XFF,0X87,0X9F,0XFF,0X00,0X7F,0XFF,0XF0,0XFF,0XFF,0XFF,0X0F,0XFF,0XFC,0X01,0XFF,
0XFF,0X91,0X9F,0XFF,0X00,0XFF,0XFF,0XE0,0X3F,0XFF,0XFE,0X03,0XFF,0XFE,0XE8,0XFF,
0XFF,0X98,0X9F,0XFF,0XCF,0XFF,0XFF,0XE7,0X3F,0XFF,0XFE,0X73,0XFF,0XFC,0XE4,0XFF,
0XFF,0X9E,0X1F,0XFF,0XFF,0XFF,0XFF,0XE7,0X3F,0XFF,0XFE,0X73,0XFF,0XFC,0XE4,0XFF,
0XFF,0X9F,0X1F,0XFE,0X40,0X7F,0XFF,0XF7,0X7F,0XFF,0XFF,0X77,0XFF,0XFC,0X04,0XFF,
0XFF,0X9F,0X9F,0XFE,0X40,0X7F,0XFF,0XE0,0X07,0XFF,0XFE,0X00,0X7F,0XFF,0X0F,0XFF,
0XFF,0XFF,0XFF,0XFF,0XFF,0XFF,0XFF,0XE0,0X07,0XFF,0XFE,0X00,0X7F,0XFF,0XFF,0XFF,
0XFF,0XE0,0X7F,0XFF,0XFF,0XFF,0XFF,0XFF,0XFF,0XFF,0XFF,0XFF,0XFF,0XFF,0XFF,0XFF,
0XFF,0X80,0X3F,0XFF,0XE0,0X7F,0XFF,0XFF,0XFF,0XFF,0XFF,0XFF,0XFF,0XFE,0X07,0XFF,
0XFF,0X9D,0X9F,0XFF,0XC0,0X7F,0XFF,0XFF,0XFF,0XFF,0XFF,0XFF,0XFF,0XFC,0X07,0XFF,
0XFF,0X9C,0X9F,0XFF,0XCF,0XFF,0XFF,0XFF,0XFF,0XFF,0XFF,0XFF,0XFF,0XFC,0XFF,0XFF,
0XFF,0X80,0X9F,0XFF,0XEF,0XFF,0XFF,0XFF,0XFF,0XFF,0XFF,0XFF,0XFF,0XFE,0XFF,0XFF,
0XFF,0XE1,0XFF,0XFE,0X00,0X7F,0XFF,0X33,0X3F,0XFF,0XF8,0XC7,0XFF,0XFC,0X07,0XFF,
0XFF,0XFF,0XFF,0XFE,0X00,0X7F,0XFF,0X33,0X3F,0XFF,0XF0,0X03,0XFF,0XFC,0X07,0XFF,
0XFF,0XFF,0XFF,0XFF,0XFF,0XFF,0XFF,0X33,0X3F,0XFF,0XF7,0X3B,0XFF,0XFF,0XFF,0XFF,
0XFF,0XC3,0X9F,0XFF,0XC7,0XFF,0XFF,0X33,0X3F,0XFF,0XF7,0X3B,0XFF,0XFF,0XFF,0XFF,
0XFF,0X81,0X9F,0XFF,0XC0,0XFF,0XFF,0X00,0X3F,0XFF,0XF7,0X3B,0XFF,0XE4,0X07,0XFF,
0XFF,0X98,0X9F,0XFF,0XF8,0X7F,0XFF,0X00,0X3F,0XFF,0XF0,0X03,0XFF,0XE4,0X07,0XFF,
0XFF,0X9C,0X1F,0XFF,0XF8,0X7F,0XFF,0XFF,0XFF,0XFF,0XF8,0XC7,0XFF,0XFF,0XFF,0XFF,
0XFF,0X9E,0X1F,0XFF,0XC0,0XFF,0XFF,0XFF,0XFF,0XFF,0XFF,0XFF,0XFF,0XFC,0XE7,0XFF,
0XFF,0XCF,0X1F,0XFF,0XC7,0XFF,0XFF,0XFF,0XFF,0XFF,0XFF,0XFF,0XFF,0XFC,0XE7,0XFF,
0XFF,0XFF,0XFF,0XFF,0XC1,0XFF,0XFF,0XFF,0XFF,0XFF,0XF8,0X73,0XFF,0XF0,0X07,0XFF,
0XFF,0XE0,0X7F,0XFF,0XF8,0X7F,0XFF,0XFF,0XFF,0XFF,0XF0,0X33,0XFF,0XF0,0X0F,0XFF,
0XFF,0XC0,0X3F,0XFF,0XF8,0X7F,0XFF,0XFF,0XFF,0XFF,0XF3,0X13,0XFF,0XFC,0XFF,0XFF,
0XFF,0X8F,0X1F,0XFF,0XC1,0XFF,0XFF,0XF0,0X3F,0XFF,0XF3,0X83,0XFF,0XFF,0XFF,0XFF,
0XFF,0X9F,0X9F,0XFF,0XCF,0XFF,0XFF,0XE0,0X3F,0XFF,0XF3,0XC3,0XFF,0XFC,0XFF,0XFF,
0XFF,0X8F,0X1F,0XFF,0XFF,0XFF,0XFF,0XE7,0XFF,0XFF,0XF9,0XE3,0XFF,0XFE,0XFF,0XFF,
0XFF,0XC0,0X3F,0XFF,0XFF,0XFF,0XFF,0XF7,0XFF,0XFF,0XFF,0XFF,0XFF,0XFC,0X07,0XFF,
0XFF,0XE0,0X7F,0XFF,0XFF,0XFF,0XFF,0X00,0X3F,0XFF,0XFF,0XFF,0XFF,0XFC,0X07,0XFF,
0XFF,0XFF,0XFF,0XFF,0XFF,0XFF,0XFF,0X00,0X3F,0XFF,0XFF,0XFF,0XFF,0XFF,0XFF,0XFF,
0XFF,0X8F,0XFF,0XFF,0XFF,0XFF,0XFF,0XFF,0XFF,0XFF,0XFF,0XFF,0XFF,0XFF,0XFF,0XFF,
0XFF,0X81,0XFF,0XFF,0XFF,0X7F,0XFF,0XE6,0X3F,0XFF,0XF0,0X03,0XFF,0XFE,0X1F,0XFF,
0XFF,0XE0,0X1F,0XFF,0XFF,0X1F,0XFF,0XE7,0X3F,0XFF,0XF0,0X03,0XFF,0XFC,0X0F,0XFF,
0XFF,0XFE,0X1F,0XFF,0XFF,0X1F,0XFF,0XE7,0X3F,0XFF,0XFB,0XFF,0XFF,0XFC,0XE7,0XFF,
0XFF,0XFE,0X1F,0XFF,0XFF,0X7F,0XFF,0XE3,0X3F,0XFF,0XF9,0XFF,0XFF,0XFC,0XE7,0XFF,
0XFF,0XC0,0X7F,0XFF,0XCE,0X7F,0XFF,0XF0,0X7F,0XFF,0XFF,0XFF,0XFF,0XFC,0XE7,0XFF,
0XFF,0X83,0XFF,0XFF,0XC4,0X7F,0XFF,0XF8,0XFF,0XFF,0XFF,0XFF,0XFF,0XFE,0X07,0XFF,
0XFF,0X83,0XFF,0XFF,0XE0,0XFF,0XFF,0XFF,0XFF,0XFF,0XFF,0XFF,0XFF,0XFF,0X0F,0XFF,
0XFF,0XE0,0X7F,0XFF,0XFB,0XFF,0XFF,0XFF,0XFF,0XFF,0XFE,0XE7,0XFF,0XFF,0XFF,0XFF,
0XFF,0XFE,0X1F,0XFE,0X00,0X7F,0XFF,0XF0,0X3F,0XFF,0XFF,0X4F,0XFF,0XFF,0XFF,0XFF,
0XFF,0XFC,0X1F,0XFE,0X00,0X7F,0XFF,0XE0,0X3F,0XFF,0XFF,0X1F,0XFF,0XFE,0X1F,0XFF,
0XFF,0XC0,0X3F,0XFF,0XFF,0XFF,0XFF,0XE7,0XFF,0XFF,0XFF,0X9F,0XFF,0XFC,0X07,0XFF,
0XFF,0X81,0XFF,0XFF,0XCC,0X7F,0XFF,0XF7,0XFF,0XFF,0XFF,0X6F,0XFF,0XFC,0XE7,0XFF,
0XFF,0X9F,0XFF,0XFF,0XCE,0X7F,0XFF,0XE0,0X3F,0XFF,0XFE,0XF7,0XFF,0XFC,0XE7,0XFF,
0XFF,0X99,0X9F,0XFF,0XCE,0X7F,0XFF,0XE0,0X3F,0XFF,0XFF,0XFF,0XFF,0XFE,0XEF,0XFF,
0XFF,0X99,0X9F,0XFF,0XC6,0X7F,0XFF,0XFF,0XFF,0XFF,0XFF,0XFF,0XFF,0XFC,0X00,0XFF,
0XFF,0X99,0X9F,0XFF,0XE0,0XFF,0XFF,0XFF,0XFF,0XFF,0XFF,0X0F,0XFF,0XFC,0X00,0XFF,
0XFF,0X99,0X9F,0XFF,0XF1,0XFF,0XFF,0X20,0X3F,0XFF,0XF2,0X07,0XFF,0XFF,0XFF,0XFF,
0XFF,0X80,0X1F,0XFF,0XFF,0XFF,0XFF,0X20,0X3F,0XFF,0XF2,0X73,0XFF,0XFF,0XFF,0XFF,
0XFF,0X80,0X1F,0XFF,0XFF,0XFF,0XFF,0XFF,0XFF,0XFF,0XF2,0X73,0XFF,0XFE,0X1F,0XFF,
0XFF,0XFF,0XFF,0XFF,0XE0,0X7F,0XFF,0XFF,0XFF,0XFF,0XF1,0X73,0XFF,0XFC,0X07,0XFF,
0XFF,0XFF,0XFF,0XFF,0XC0,0X7F,0XFF,0XC0,0XFF,0XFF,0XF8,0X07,0XFF,0XFC,0XE7,0XFF,
0XFF,0XE0,0XFF,0XFF,0XCA,0XFF,0XFF,0X00,0X7F,0XFF,0XFE,0X0F,0XFF,0XFC,0XE7,0XFF,
0XFF,0XC0,0X3F,0XFF,0XCA,0X7F,0XFF,0X3B,0X3F,0XFF,0XFF,0XFF,0XFF,0XFE,0XEF,0XFF,
0XFF,0X8F,0X3F,0XFF,0XCA,0X7F,0XFF,0X39,0X3F,0XFF,0XFF,0XFF,0XFF,0XFC,0X00,0XFF,
0XFF,0X9F,0X9F,0XFF,0XC8,0X7F,0XFF,0X01,0X3F,0XFF,0XFC,0X0F,0XFF,0XFC,0X00,0XFF,
0XFF,0X9F,0X9F,0XFF,0XFC,0XFF,0XFF,0XC3,0XFF,0XFF,0XF0,0X07,0XFF,0XFF,0XFF,0XFF,
0XFF,0X9F,0X9F,0XFF,0XFF,0XFF,0XFF,0XFF,0XFF,0XFF,0XF3,0XB3,0XFF,0XFF,0XFF,0XFF,
0XFF,0X80,0X1F,0XFE,0X00,0X7F,0XFF,0XFF,0XFF,0XFF,0XF3,0X93,0XFF,0XFC,0X07,0XFF,
0XFF,0X80,0X1F,0XFE,0X00,0X7F,0XFF,0XFF,0X3F,0XFF,0XF0,0X13,0XFF,0XFC,0X07,0XFF,
0XFF,0XFF,0XFF,0XFF,0XFF,0XFF,0XFF,0XFF,0X3F,0XFF,0XFC,0X3F,0XFF,0XFF,0XEF,0XFF,
0XFF,0XFF,0XFF,0XFF,0XFF,0XFF,0XFF,0XFF,0XFF,0XFF,0XFF,0XFF,0XFF,0XFF,0XE7,0XFF,
0XFF,0X88,0X3F,0XFF,0XE1,0XFF,0XFF,0XFF,0XFF,0XFF,0XFF,0XFF,0XFF,0XFC,0X07,0XFF,
0XFF,0X98,0X1F,0XFF,0XC0,0X7F,0XFF,0X87,0X3F,0XFF,0XF8,0X73,0XFF,0XFC,0X0F,0XFF,
0XFF,0X99,0X9F,0XFF,0XCE,0X7F,0XFF,0X03,0X3F,0XFF,0XF0,0X33,0XFF,0XFF,0XFF,0XFF,
0XFF,0X99,0X9F,0XFF,0XCE,0X7F,0XFF,0X31,0X3F,0XFF,0XF3,0X13,0XFF,0XFC,0XCF,0XFF,
0XFF,0X9F,0X9F,0XFF,0XEE,0XFF,0XFF,0X38,0X3F,0XFF,0XF3,0X83,0XFF,0XFC,0X87,0XFF,
0XFF,0XCF,0X1F,0XFE,0X00,0X7F,0XFF,0X3C,0X3F,0XFF,0XF3,0XC3,0XFF,0XFC,0X87,0XFF,
0XFF,0XC0,0X3F,0XFE,0X00,0X7F,0XFF,0X9E,0X3F,0XFF,0XF9,0XE3,0XFF,0XFC,0X27,0XFF,
0XFF,0XF0,0X7F,0XFF,0XFF,0XFF,0XFF,0XFF,0XFF,0XFF,0XFF,0XFF,0XFF,0XFE,0X27,0XFF,
0XFF,0XFF,0XFF,0XFF,0XFF,0XFF,0XFF,0XFF,0XFF,0XFF,0XFF,0XFF,0XFF,0XFF,0XFF,0XFF,
0XFF,0XFF,0XFF,0XFF,0XFF,0XFF,0XFF,0XFF,0XFF,0XFF,0XFF,0XFF,0XFF,0XFF,0XFF,0XFF,
0XFF,0XFF,0XFF,0XFF,0XFF,0XFF,0XFF,0XFF,0XFF,0XFF,0XFF,0XFF,0XFF,0XFF,0XFF,0XFF,
0XFF,0XFF,0XFF,0XFF,0XFF,0XFF,0XFF,0XFF,0XFF,0XFF,0XFF,0XFF,0XFF,0XFF,0XFF,0XFF,
0XFF,0XFF,0XFF,0XFF,0XFF,0XFF,0XFF,0XFF,0XFF,0XFF,0XFF,0XFF,0XFF,0XFF,0XFF,0XFF,
0XFF,0XFF,0XFF,0XFF,0XFF,0XFF,0XFF,0XFF,0XFF,0XFF,0XFF,0XFF,0XFF,0XFF,0XFF,0XFF,
0XFF,0XFF,0XFF,0XFF,0XFF,0XFF,0XFF,0XFF,0XFF,0XFF,0XFF,0XFF,0XFF,0XFF,0XFF,0XFF,
0XF8,0X00,0X00,0X00,0X00,0X3F,0XFF,0XFF,0XFF,0XFF,0XFF,0XBF,0XFF,0XFF,0XFF,0XFF,
0XF8,0X00,0X00,0X00,0X00,0X3F,0XFF,0XFF,0XFF,0XFF,0XFF,0XBF,0XFF,0XFF,0XFF,0XFF,
0XF8,0X00,0X00,0X00,0X00,0X1F,0XFF,0XFF,0XFF,0XFF,0XFF,0X3F,0XF0,0X7F,0XC1,0XFF,
0XF8,0X00,0X00,0X00,0X00,0X1F,0XFF,0XFF,0XFF,0XFF,0XFF,0X3F,0XF0,0X7F,0XC1,0XFF,
0XF8,0X00,0X00,0X00,0X00,0X0F,0XFF,0XFF,0XFF,0XFF,0XFE,0X3F,0XF0,0XFF,0XE1,0XFF,
0XF8,0X00,0X00,0X00,0X00,0X0F,0XFF,0XFF,0XFF,0XFF,0XFE,0X3F,0XF0,0XFF,0XE0,0XFF,
0XF8,0X00,0X00,0X00,0X00,0X07,0XFF,0XFF,0XFF,0XFF,0XFE,0X3F,0XF0,0XFF,0XF0,0XFF,
0XF8,0X00,0X00,0X00,0X00,0X03,0XFF,0XFF,0XFF,0XFF,0XFC,0X3F,0XF0,0XFF,0XF0,0XFF,
0XF8,0X00,0X00,0X00,0X00,0X03,0XFF,0XFF,0XFF,0XFF,0XFC,0X3F,0XF0,0XFF,0XE0,0XFF,
0XF8,0X00,0X00,0X00,0X00,0X01,0XFF,0XFF,0XFF,0XFF,0XF8,0X3F,0XF0,0X7F,0XE0,0XFF,
0XF8,0X00,0X00,0X00,0X00,0X01,0XFF,0XFF,0XFF,0XFF,0XF8,0X3F,0XF0,0X7F,0XC1,0XFF,
0XF8,0X00,0X00,0X00,0X00,0X00,0XFF,0XFF,0XFF,0XFF,0XF8,0X3F,0XF0,0X3F,0X81,0XFF,
0XF8,0X00,0X00,0X00,0X00,0X00,0XFF,0XFF,0XFF,0XFF,0XF0,0X3F,0XF8,0X0E,0X01,0XFF,
0XF8,0X00,0X00,0X00,0X00,0X00,0X7F,0XFF,0XFF,0XFF,0XF0,0X3F,0XFC,0X00,0X03,0XFF,
0XF8,0X00,0X00,0X00,0X00,0X00,0X3F,0XFF,0XFF,0XFF,0XE0,0X3F,0XFC,0X00,0X03,0XFF,
0XF8,0X00,0X00,0X00,0X00,0X00,0X3F,0XFF,0XFF,0XFF,0XE0,0X3F,0XFE,0X00,0X07,0XFF,
0XF8,0X00,0X00,0X00,0X00,0X00,0X1F,0XFF,0XFF,0XFF,0XE0,0X3F,0XFF,0X80,0X0F,0XFF,
0XF8,0X00,0X00,0X00,0X00,0X00,0X1F,0XFF,0XFF,0XFF,0XE0,0X3F,0XFF,0XE0,0X7F,0XFF,
0XF8,0X00,0X00,0X00,0X00,0X00,0X1F,0XFF,0XFF,0XFF,0XE0,0X3F,0XFF,0XFF,0XFF,0XFF,
0XF8,0X00,0X00,0X00,0X00,0X00,0X0F,0XFF,0XFF,0XFF,0XC0,0X3F,0XFF,0XFF,0XFF,0XFF,
0XF8,0X00,0X00,0X00,0X00,0X00,0X0F,0XFF,0XFF,0XFF,0XC0,0X3F,0XF0,0X7F,0XC1,0XFF,
0XF8,0X00,0X00,0X00,0X00,0X00,0X07,0XFF,0XFF,0XFF,0X80,0X3F,0XF0,0XFF,0XE1,0XFF,
0XF8,0X00,0X00,0X00,0X00,0X00,0X07,0XFF,0XFF,0XFF,0X80,0X3F,0XF0,0XFF,0XE1,0XFF,
0XF8,0X00,0X00,0X00,0X00,0X00,0X03,0XFF,0XFF,0XFF,0X80,0X3F,0XF0,0XFF,0XF0,0XFF,
0XF8,0X00,0X00,0X00,0X00,0X00,0X01,0XFF,0XFF,0XFF,0X00,0X3F,0XF0,0XFF,0XF0,0XFF,
0XF8,0X00,0X00,0X00,0X00,0X00,0X01,0XFF,0XFF,0XFF,0X00,0X3F,0XF0,0XFF,0XF0,0XFF,
0XF8,0X00,0X00,0X00,0X00,0X00,0X00,0XFF,0XFF,0XFF,0X00,0X3F,0XF0,0XFF,0XE0,0XFF,
0XF8,0X00,0X00,0X00,0X00,0X00,0X00,0X7F,0XFF,0XFE,0X00,0X3F,0XF0,0X7F,0XE0,0XFF,
0XF8,0X00,0X00,0X00,0X00,0X00,0X00,0X7F,0XFF,0XFC,0X00,0X3F,0XF0,0X1F,0X81,0XFF,
0XF8,0X00,0X00,0X00,0X00,0X00,0X00,0X3F,0XFF,0XF8,0X00,0X3F,0XF8,0X00,0X01,0XFF,
0XF8,0X00,0X00,0X00,0X00,0X00,0X00,0X1F,0XFF,0XF8,0X00,0X3F,0XFC,0X00,0X03,0XFF,
0XF8,0X00,0X00,0X00,0X00,0X00,0X00,0X1F,0XFF,0XF8,0X00,0X3F,0XFE,0X00,0X07,0XFF,
0XF8,0X00,0X00,0X00,0X00,0X00,0X00,0X0F,0XFF,0XF0,0X00,0X3F,0XFF,0X00,0X0F,0XFF,
0XF8,0X00,0X00,0X00,0X00,0X00,0X00,0X0F,0XFF,0XF0,0X00,0X3F,0XFF,0XC0,0X3F,0XFF,
0XF8,0X00,0X00,0X00,0X00,0X00,0X00,0X07,0XFF,0XE0,0X00,0X3F,0XFF,0XFF,0XFF,0XFF,
0XF8,0X00,0X00,0X00,0X00,0X00,0X00,0X07,0XFF,0XE0,0X00,0X3F,0XFF,0XFF,0XFF,0XFF,
0XF8,0X00,0X00,0X40,0X00,0X00,0X00,0X03,0XFF,0XE0,0X00,0X3F,0XFF,0XFF,0XE1,0XFF,
0XF8,0X00,0X00,0X40,0X00,0X00,0X00,0X03,0XFF,0XC0,0X00,0X3F,0XFF,0XFF,0XC0,0XFF,
0XF8,0X00,0X00,0X60,0X00,0X00,0X00,0X01,0XFF,0XC0,0X00,0X3F,0XFF,0XFF,0XC0,0XFF,
0XF8,0X00,0X00,0XE0,0X00,0X00,0X00,0X00,0XFF,0X80,0X00,0X3F,0XFF,0XFF,0XC0,0XFF,
0XF8,0X00,0X00,0XF0,0X00,0X00,0X00,0X00,0XFF,0X80,0X00,0X3F,0XFF,0XFF,0XE1,0XFF,
0XF8,0X00,0X01,0XF0,0X00,0X00,0X00,0X00,0X7F,0X80,0X00,0X3F,0XFF,0XFF,0XFF,0XFF,
0XF8,0X00,0X01,0XF8,0X00,0X00,0X00,0X00,0X3F,0X00,0X00,0X3F,0XFF,0XFF,0XFF,0XFF,
0XF8,0X00,0X01,0XFC,0X00,0X00,0X00,0X00,0X3F,0X00,0X00,0X3F,0XFF,0XC0,0X7F,0XFF,
0XF8,0X00,0X03,0XFC,0X00,0X00,0X00,0X00,0X1E,0X00,0X00,0X3F,0XFF,0X00,0X1F,0XFF,
0XF8,0X00,0X03,0XFE,0X00,0X00,0X00,0X00,0X1E,0X00,0X00,0X3F,0XFE,0X00,0X07,0XFF,
0XF8,0X00,0X07,0XFE,0X00,0X00,0X00,0X00,0X0E,0X00,0X00,0X3F,0XFC,0X00,0X03,0XFF,
0XF8,0X00,0X07,0XFF,0X00,0X00,0X00,0X00,0X04,0X00,0X00,0X3F,0XF8,0X00,0X03,0XFF,
0XF8,0X00,0X07,0XFF,0X00,0X00,0X00,0X00,0X04,0X00,0X00,0X3F,0XF0,0X1F,0X01,0XFF,
0XF8,0X00,0X0F,0XFF,0X80,0X00,0X00,0X00,0X00,0X00,0X00,0X3F,0XF0,0X7F,0XC1,0XFF,
0XF8,0X00,0X0F,0XFF,0XC0,0X00,0X00,0X00,0X00,0X00,0X00,0X3F,0XF0,0X7F,0XE0,0XFF,
0XF8,0X00,0X1F,0XFF,0XC0,0X00,0X00,0X00,0X00,0X00,0X00,0X3F,0XF0,0XFF,0XE0,0XFF,
0XF8,0X00,0X1F,0XFF,0XE0,0X00,0X00,0X00,0X00,0X00,0X00,0X3F,0XF0,0XFF,0XF0,0XFF,
0XF8,0X00,0X1F,0XFF,0XF0,0X00,0X00,0X00,0X00,0X00,0X00,0X3F,0XF0,0XFF,0XF0,0XFF,
0XF8,0X00,0X1F,0XFF,0XF0,0X00,0X00,0X00,0X00,0X00,0X00,0X3F,0XF0,0XFF,0XE0,0XFF,
0XF8,0X00,0X3F,0XFF,0XF8,0X00,0X00,0X00,0X00,0X00,0X00,0X3F,0XF0,0X7F,0XC1,0XFF,
0XF8,0X00,0X3F,0XFF,0XF8,0X00,0X00,0X00,0X00,0X00,0X00,0X3F,0XF0,0X1F,0X81,0XFF,
0XF8,0X00,0X3F,0XFF,0XFC,0X00,0X00,0X00,0X00,0X00,0X00,0X3F,0XF8,0X00,0X01,0XFF,
0XF8,0X00,0X7F,0XFF,0XFC,0X00,0X00,0X00,0X00,0X00,0X00,0X3F,0XFC,0X00,0X03,0XFF,
0XF8,0X00,0X7F,0XFF,0XFE,0X00,0X00,0X00,0X00,0X00,0X00,0X3F,0XFE,0X00,0X07,0XFF,
0XF8,0X00,0XFF,0XFF,0XFF,0X00,0X00,0X00,0X00,0X00,0X00,0X3F,0XFF,0X00,0X0F,0XFF,
0XF8,0X00,0XFF,0XFF,0XFF,0X00,0X00,0X00,0X00,0X00,0X00,0X3F,0XFF,0XC0,0X3F,0XFF,
0XF8,0X00,0XFF,0XFF,0XFF,0X80,0X00,0X00,0X00,0X00,0X00,0X3F,0XFF,0XFF,0XFF,0XFF,
0XF8,0X01,0XFF,0XFF,0XFF,0X80,0X00,0X00,0X00,0X00,0X00,0X3F,0XFF,0XFF,0XFF,0XFF,
0XF8,0X01,0XFF,0XFF,0XFF,0XC0,0X00,0X00,0X00,0X00,0X00,0X3F,0XFF,0XFF,0XFF,0XFF,
0XF8,0X03,0XFF,0XFF,0XFF,0XC0,0X00,0X00,0X00,0X00,0X00,0X3F,0XF0,0X00,0X01,0XFF,
0XF8,0X03,0XFF,0XFF,0XFF,0XE0,0X00,0X00,0X00,0X00,0X00,0X3F,0XF0,0X00,0X01,0XFF,
0XF8,0X03,0XFF,0XFF,0XFF,0XE0,0X00,0X00,0X00,0X00,0X00,0X3F,0XF0,0X00,0X01,0XFF,
0XF8,0X07,0XFF,0XFF,0XFF,0XF0,0X00,0X00,0X00,0X00,0X00,0X3F,0XF0,0X00,0X01,0XFF,
0XF8,0X07,0XFF,0XFF,0XFF,0XF8,0X00,0X00,0X00,0X00,0X00,0X3F,0XF0,0X00,0X01,0XFF,
0XF8,0X0F,0XFF,0XFF,0XFF,0XF8,0X00,0X00,0X00,0X00,0X00,0X3F,0XFF,0XFF,0XFF,0XFF,
0XF8,0X0F,0XFF,0XFF,0XFF,0XFC,0X00,0X00,0X00,0X00,0X00,0X3F,0XFF,0XFF,0XFF,0XFF,
0XF8,0X1F,0XFF,0XFF,0XFF,0XFE,0X00,0X00,0X00,0X00,0X00,0X3F,0XF0,0XFF,0XE1,0XFF,
0XF8,0X1F,0XFF,0XFF,0XFF,0XFF,0X00,0X00,0X00,0X00,0X00,0X3F,0XF0,0X1F,0XE1,0XFF,
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
void loop() {
  Power_on();
  Send_Pic(black_data_head,Pic_Black);
  Send_Pic(red_data_head, Pic_Black_Red);
  delay(8000);
  delay(8000);
  delay(8000);
  Power_off();
  while(1);
}
void Power_on()
{
  IO.digitalWrite(2,HIGH);
  delay(1000);
  }
  
void Power_off()
{
  IO.digitalWrite(2,LOW);
  }
  
void Send_Pic(unsigned char *data_head, unsigned char *pic)
{
  unsigned int i = 0,j = 0,n = 0;
  unsigned char f=0;
  Wire.beginTransmission(slave_addr); // transmit to device slave_addr
  Wire.write(data_head,6);
  Wire.endTransmission();    // stop transmitting
  for(i=0,n=0;i<592;i++)
  {
  Wire.beginTransmission(slave_addr); // transmit to device slave_addr
  for(j=0;j<8;j++)
  {
    f=pgm_read_word_near((pic+n));
    n++;
    Wire.write(f);
  Serial.println(f); 
    }
   Wire.endTransmission();    // stop transmitting
  }   
  Serial.println(n);
  }

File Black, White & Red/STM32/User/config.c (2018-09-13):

#include "stm32f10x.h"
#include "config.h"
#define  ClockSpeed      400000
extern EventStatus i2c_event;
extern EventStatus i2c_event;
ErrorStatus HSEStartUpStatus;
NVIC_InitTypeDef NVIC_InitStructure;
EventStatus i2c_event= NOEVENT;
I2C_InitTypeDef   I2C_InitStructure;
extern u8 I2C_SLAVE_ADDRESS7;
extern unsigned char Black_Data_I2C1_Buffer_Rx[5000];
extern unsigned char Red_Data_I2C1_Buffer_Rx[5000];
void driver_delay_us(unsigned int xus)
{
	for(;xus>1;xus--);
}

void driver_delay_xms(unsigned long xms)	
{	
    unsigned long i = 0 , j=0;

    for(j=0;j<xms;j++)
	{
        for(i=0; i<256; i++);
    }
}

/*******************************************************************************
* Function Name  : RCC_Configuration
* Description    : Configures the different system clocks.
* Input          : None
* Output         : None
* Return         : None
*******************************************************************************/
void RCC_Configuration(void)
{
 
  RCC_DeInit();
 

  RCC_HSEConfig(RCC_HSE_ON);
  

  HSEStartUpStatus = RCC_WaitForHSEStartUp();
  if(HSEStartUpStatus == SUCCESS)
  {
    // PLLCLK = 8MHz * 9 = 72 MHz 
    RCC_PLLConfig(RCC_PLLSource_HSE_Div1, RCC_PLLMul_9);
  }
  else {

    RCC_HSICmd(ENABLE);

    while(RCC_GetFlagStatus(RCC_FLAG_HSIRDY) == RESET);


    RCC_PLLConfig(RCC_PLLSource_HSI_Div2,RCC_PLLMul_16);
  }


  FLASH_PrefetchBufferCmd(FLASH_PrefetchBuffer_Enable);


  FLASH_SetLatency(FLASH_Latency_2);
	

  RCC_HCLKConfig(RCC_SYSCLK_Div1); 


  RCC_PCLK2Config(RCC_HCLK_Div1); 


  RCC_PCLK1Config(RCC_HCLK_Div2);
  

  RCC_PLLCmd(ENABLE);
  

  while(RCC_GetFlagStatus(RCC_FLAG_PLLRDY) == RESET);
  

  RCC_SYSCLKConfig(RCC_SYSCLKSource_PLLCLK);
  

  while(RCC_GetSYSCLKSource() != 0x08);
    
  RCC_APB2PeriphClockCmd(RCC_APB2Periph_GPIOA |
            RCC_APB2Periph_USART1|RCC_APB2Periph_AFIO,
            ENABLE);
}


/*******************************************************************************
* Function       : GPIO_Configuration
* Description    : Configures GPIO
* Input          : None
* Output         : None
* Return         : None
*******************************************************************************/
void GPIO_Configuration(void)
{
  GPIO_InitTypeDef GPIO_InitStructure;

  RCC_APB2PeriphClockCmd(RCC_APB2Periph_GPIOA | RCC_APB2Periph_AFIO, ENABLE);
  GPIO_InitStructure.GPIO_Pin = GPIO_Pin_7 | GPIO_Pin_5 |GPIO_Pin_6;    
  GPIO_InitStructure.GPIO_Speed = GPIO_Speed_2MHz;
  GPIO_InitStructure.GPIO_Mode = GPIO_Mode_Out_PP;
  GPIO_Init(GPIOA, &GPIO_InitStructure);
	
	GPIO_InitStructure.GPIO_Pin =GPIO_Pin_0;	 //PA.0
	GPIO_InitStructure.GPIO_Mode =GPIO_Mode_IPD;//input
	GPIO_Init(GPIOA, &GPIO_InitStructure);	//Init IO
	
	GPIO_InitStructure.GPIO_Pin =GPIO_Pin_1 | GPIO_Pin_2;	 //PA.1,2
	GPIO_InitStructure.GPIO_Mode =GPIO_Mode_IPD;
	GPIO_Init(GPIOA, &GPIO_InitStructure);	

  RCC_APB2PeriphClockCmd(RCC_APB2Periph_GPIOB, ENABLE);
  GPIO_InitStructure.GPIO_Pin = GPIO_Pin_11 | GPIO_Pin_8 |GPIO_Pin_9;    
  GPIO_InitStructure.GPIO_Speed = GPIO_Speed_2MHz;
  GPIO_InitStructure.GPIO_Mode = GPIO_Mode_Out_PP;
  GPIO_Init(GPIOB, &GPIO_InitStructure);
	
	GPIO_InitStructure.GPIO_Pin =GPIO_Pin_3;	 //PB.3
	GPIO_InitStructure.GPIO_Mode =GPIO_Mode_IPD;
	GPIO_Init(GPIOB, &GPIO_InitStructure);	

  GPIO_InitStructure.GPIO_Pin = GPIO_Pin_10;    
  GPIO_InitStructure.GPIO_Speed = GPIO_Speed_2MHz;
  GPIO_InitStructure.GPIO_Mode = GPIO_Mode_IN_FLOATING;
  GPIO_Init(GPIOB, &GPIO_InitStructure);
	
	GPIO_InitStructure.GPIO_Pin =  GPIO_Pin_6 | GPIO_Pin_7;
	GPIO_InitStructure.GPIO_Speed = GPIO_Speed_50MHz;
	GPIO_InitStructure.GPIO_Mode = GPIO_Mode_AF_OD;
  GPIO_Init(GPIOB, &GPIO_InitStructure);
	
	GPIO_InitStructure.GPIO_Pin =  GPIO_Pin_0 | GPIO_Pin_1 |GPIO_Pin_2;    //input
	GPIO_InitStructure.GPIO_Speed = GPIO_Speed_50MHz;
	GPIO_InitStructure.GPIO_Mode = GPIO_Mode_IN_FLOATING;
  GPIO_Init(GPIOB, &GPIO_InitStructure);
	
}
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

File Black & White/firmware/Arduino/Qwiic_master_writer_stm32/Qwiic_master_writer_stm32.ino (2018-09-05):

// Wire Master Writer
// by Nicholas Zambetti <http://www.zambetti.com>

// Demonstrates use of the Wire library
// Writes data to an I2C/TWI slave device
// Refer to the "Wire Slave Receiver" example for use with this

// Created 29 March 2006

// This example code is in the public domain.
#include"QWIICGDE029A1.h"
#include <Wire.h>
const unsigned char logo[] PROGMEM = {
0xFF,0xFF,0xFF,0xFF,0xFF,0xFF,0xFF,0xFF,0xFF,0xFF,0xFF,0xFF,0xFF,0xFF,0xFF,0xFF,
0xFF,0xFF,0xFF,0xFF,0xFF,0xFF,0xFF,0xFF,0xFF,0xFF,0xFF,0xFF,0xFF,0xFF,0xFF,0xFF,
0xFF,0xFF,0xFF,0xFF,0xFF,0xFF,0xFF,0xFF,0xFF,0xFF,0xFF,0xFF,0xFF,0xFF,0xFF,0xFF,
0xFF,0xFF,0xFF,0xFF,0xFF,0xFF,0xFF,0xFF,0xFF,0xFF,0xFF,0xFF,0xFF,0xFF,0xFF,0xFF,
0xFF,0xFF,0xFF,0xFF,0xFF,0xFF,0xFF,0xFF,0xFF,0xFF,0xFF,0xFF,0xFF,0xFF,0xFF,0xFF,
0xFF,0xFF,0xFF,0xFF,0xFF,0xFF,0xFF,0xFF,0xFF,0xFF,0xFF,0xFF,0xFF,0xFF,0xFF,0xFF,
0xFF,0xFF,0xFF,0xFF,0xFF,0xFF,0xFF,0xFF,0xFF,0xFF,0xFF,0xFF,0xFF,0xFF,0xFF,0xFF,
0xFF,0xFF,0xFF,0xFF,0xFF,0xFF,0xFF,0xFF,0xFF,0xFF,0xFF,0xFF,0xFF,0xFF,0xFF,0xFF,
0xFF,0xFF,0xFF,0xFF,0xFF,0xFF,0xFF,0xFF,0xFF,0xFF,0xFF,0xFF,0xFF,0xFF,0xFF,0xFF,
0xFF,0xFF,0xFF,0xFF,0xFF,0xFF,0xFF,0xFF,0xFF,0xFF,0xFF,0xFF,0xFF,0xFF,0xFF,0xFF,
0xFF,0xFF,0xFF,0xFF,0xFF,0xFF,0xFF,0xFF,0xFF,0xFF,0xFF,0xFF,0xFF,0xFF,0xFF,0xFF,
0xFF,0xFF,0xFF,0xFF,0xFF,0xFF,0xFF,0xFF,0xFF,0xFF,0xFF,0xFF,0xFF,0xFF,0xFF,0xFF,
0xFF,0xFF,0xFF,0xFF,0xFF,0xFF,0xFF,0xFF,0xFF,0xFF,0xFF,0xFF,0xFF,0xFF,0xFF,0xFF,
0xFF,0xFF,0xFF,0xFF,0xFF,0xFF,0xFF,0xFF,0xFF,0xFF,0xFF,0xFF,0xFF,0xFF,0xFF,0xFF,
0xFF,0xFF,0xFF,0xFF,0xFF,0xFF,0xFF,0xFF,0xFF,0xFF,0xFF,0xFF,0xFF,0xFF,0xFF,0xFF,
0xFF,0xFF,0xFF,0xFF,0xFF,0xFF,0xFF,0xFF,0xFF,0xFF,0xFF,0xFF,0xFF,0xFF,0xFF,0xFF,
0xFF,0xFF,0xFF,0xFF,0xFF,0xFF,0xFF,0xFF,0xFF,0xFF,0xFF,0xFF,0xFF,0xFF,0xFF,0xFF,
0xFF,0xFF,0xFF,0xFF,0xFF,0xFF,0xFF,0xFF,0xFF,0xFF,0xFF,0xFF,0xFF,0xFF,0xFF,0xFF,
0xFF,0xFF,0xFF,0xFF,0xFF,0xFF,0xFF,0xFF,0xFF,0xFF,0xFF,0xFF,0xFF,0xFF,0xFF,0xFF,
0xFF,0xFF,0xFF,0xFF,0xFF,0xFF,0xFF,0xFF,0xFF,0xFF,0xFF,0xFF,0xFF,0xFF,0xFF,0xFF,
0xFF,0xFF,0xFF,0xFF,0x80,0x00,0x00,0x00,0x00,0x03,0xFF,0xFF,0xFF,0xFF,0xFF,0xFF,
0xFF,0xFF,0xFF,0xFF,0x80,0x00,0x00,0x00,0x00,0x03,0xFF,0xFF,0xFF,0xFF,0xFF,0xFF,
0xFF,0xFF,0xFF,0xFF,0x80,0x7F,0xFF,0xFF,0xF8,0x03,0xFF,0xFF,0xFF,0xFF,0xFF,0xFF,
0xFF,0xFF,0xFF,0xFF,0x83,0xFF,0xFF,0xFF,0xFF,0x03,0xFF,0xFF,0xFF,0xFF,0xFF,0xFF,
0xFF,0xFF,0xFF,0xFF,0x8F,0xFF,0xFF,0xFF,0xFF,0x83,0xFF,0xFF,0xFF,0xFF,0xFF,0xFF,
0xFF,0xFF,0xFF,0xFF,0x8F,0xFF,0xFF,0xFF,0xFF,0xC3,0xFF,0x83,0xFF,0xFF,0xFF,0xFF,
0xFF,0xFF,0xFF,0xFF,0x9F,0xFF,0xFF,0xFF,0xFF,0xE3,0xFF,0x80,0x1F,0xFF,0xFF,0xFF,
0xFF,0xFF,0xFF,0xFF,0x9F,0xFF,0xFF,0xFF,0xFF,0xE3,0xFF,0x80,0x1F,0xFF,0xFF,0xFF,
0xFF,0xFF,0xFF,0xFF,0xBF,0x00,0x00,0x00,0x07,0xE3,0xFF,0x80,0x1F,0xFF,0xFF,0xFF,
0xFF,0xFF,0xFF,0xFF,0xBF,0x00,0x03,0xC0,0x03,0xE3,0xFF,0xF8,0x3F,0xFF,0xFF,0xFF,
0xFF,0xFF,0xFF,0xFF,0xBF,0x00,0x07,0xE0,0x03,0xE3,0xFF,0xE0,0xFF,0xFF,0xFF,0xFF,
0xFF,0xFF,0xFF,0xFF,0x9F,0xFE,0x07,0xFF,0xFF,0xE3,0xFF,0x83,0xFF,0xFF,0xFF,0xFF,
0xFF,0xFF,0xFF,0xFF,0x9F,0xFE,0x07,0xFF,0xFF,0xE3,0xFF,0x80,0x1F,0xFF,0xFF,0xFF,
0xFF,0xFF,0xFF,0xFF,0x9F,0xFE,0x07,0xFF,0xFF,0xC3,0xFF,0x80,0x1F,0xFF,0xFF,0xFF,
0xFF,0xFF,0xFF,0xFF,0x8F,0xFE,0x07,0xFF,0xFF,0xC3,0xFF,0xE0,0x1F,0xFF,0xFF,0xFF,
0xFF,0xFF,0xFF,0xFF,0x87,0xFE,0x07,0xFF,0xFF,0x83,0xFF,0xF8,0x1F,0xFF,0xFF,0xFF,
0xFF,0xFF,0xFF,0xFF,0x81,0xFE,0x07,0xFF,0xFE,0x03,0xFF,0xC0,0xFF,0xFF,0xFF,0xFF,
0xFF,0xFF,0xFF,0xFF,0x80,0x00,0x00,0x00,0x00,0x03,0xFF,0x83,0xFF,0xFF,0xFF,0xFF,
0xFF,0xFF,0xFF,0xFF,0x80,0x00,0x00,0x00,0x00,0x03,0xFF,0x8F,0xFF,0xFF,0xFF,0xFF,
0xFF,0xFF,0xFF,0xFF,0x80,0x00,0x00,0x00,0x00,0x03,0xFF,0xFF,0xFF,0xFF,0xFF,0xFF,
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
